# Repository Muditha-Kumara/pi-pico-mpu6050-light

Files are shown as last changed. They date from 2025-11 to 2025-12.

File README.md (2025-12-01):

# Motion Light Pico Hat

Motion Light Pico Hat Icon

An interactive dual-core LED "water flow" and tilt simulation for the Raspberry Pi Pico / Pico 2 using a WS2812B LED strip and an MPU-6050 IMU (or a built‑in software tilt simulator when the sensor is absent). The project demonstrates:

- Dual-core coordination on RP2040 (Core 0: sensor / simulation; Core 1: LED rendering + serial output)
- Smooth physics-like motion (velocity, damping, bounce) converted to a glowing LED blob that shifts and reflects within the strip
- ASCII real-time visualization in the Serial Monitor for debugging without LEDs
- Seamless fallback to simulated tilt if the accelerometer is not detected

## Supported Boards

| Board | PlatformIO Environment | Arduino IDE Board | Notes |
|---|---|---|---|
| Raspberry Pi Pico (RP2040) | `pico_official` | "Raspberry Pi Pico" (Earle Philhower core) | Fully supported |
| Raspberry Pi Pico 2 (RP2350) | `rpipico2_project` | "Raspberry Pi Pico 2" (Earle Philhower core) | Use with updated RP2350 core; see below |

*Pico 2 support uses the RP2350 chip. Logic and pin usage are identical. To enable, adjust `platformio.ini` and ensure the correct board/platform is selected.*

> **Development Note:**
> This project was requested for the original Raspberry Pi Pico (RP2040). However, all development and testing were performed on a Raspberry Pi Pico 2 (RP2350) board. The code is fully compatible with the normal Pico board and was written to ensure it works on both models. If you use a Pico 2, select the correct environment in [`platformio.ini`](./platformio.ini) or Arduino IDE as described above.

## Features

- Real-time LED physics (position, velocity, damping, reflection)
- Adaptive glow with Gaussian/exponential falloff and shimmer
- Dual-core separation: deterministic LED refresh at ~30 FPS independent of sensor loop (~50 Hz)
- Automatic hardware detection for MPU‑6050 at I2C address `0x68`; simulation fallback if absent
- Lightweight inter-core communication (volatile globals)

## Directory Structure

```
.
├── platformio.ini      # PlatformIO build configuration
├── src/
│   └── main.cpp        # Main application source (dual-core logic, PlatformIO)
├── MotionLightPicoHat_Arduino/
│   └── MotionLightPicoHat_Arduino.ino # Arduino IDE-friendly sketch (identical logic)
├── lib/                # (Optional) user libraries
├── include/            # (Optional) project headers
├── PCB/                # Hardware design files and outputs
│   ├── pico.kicad_sch      # KiCad schematic
│   ├── pico.kicad_pcb      # KiCad PCB layout
│   ├── pico.kicad_pro      # KiCad project settings
│   ├── pico.kicad_prl      # KiCad project local settings (ignore in git)
│   ├── PCB_Print/          # Gerber and drill files for manufacturing
│   │   └── pico-PCB(gbr).zip # Gerber/drill manufacturing archive for PCB fabrication
│   └── Assets/             # PCB-related images and logos
├── assets/             # Icons and images for documentation
├── README.md           # This documentation
├── LICENSE             # Project license
```

- [`MotionLightPicoHat_Arduino/`](./MotionLightPicoHat_Arduino/.) contains an Arduino IDE-friendly [`.ino`](./MotionLightPicoHat_Arduino/MotionLightPicoHat_Arduino.ino) file for easy use. Open this folder and file directly in Arduino IDE for the same functionality as [`src/main.cpp`](./src/main.cpp).

- [`PCB/`](./PCB/) contains all hardware design files: schematic, PCB layout, project settings, gerbers (in [`PCB_Print/`](./PCB/PCB_Print/)) and images.

## Hardware Requirements
## PCB Details
#### I2C Address Selection

The PCB includes a J4 jumper, which can be used to select the I2C address of the MPU-6050 sensor. By bridging or leaving J4 open, you can choose between the two standard MPU-6050 I2C addresses (0x68 or 0x69). Refer to the silkscreen and schematic for the correct configuration for your sensor module.

**Note:** The PCB is designed specifically for the original Raspberry Pi Pico (RP2040), not Pico 2. Pinout and mechanical fit are for the standard Pico board only.

This project includes a custom PCB designed for the Raspberry Pi Pico, WS2812B LED strip, and MPU-6050 IMU. The PCB provides:

- Direct Pico header footprint (solder Pico)
- Onboard or external MPU-6050 support (I2C)
- Dedicated LED strip connector (5V, GND, DIN)
- 5V power input (max 5A) and distribution
- Clear silkscreen labels for all connections

### PCB Images

**Top View (Silkscreen):**

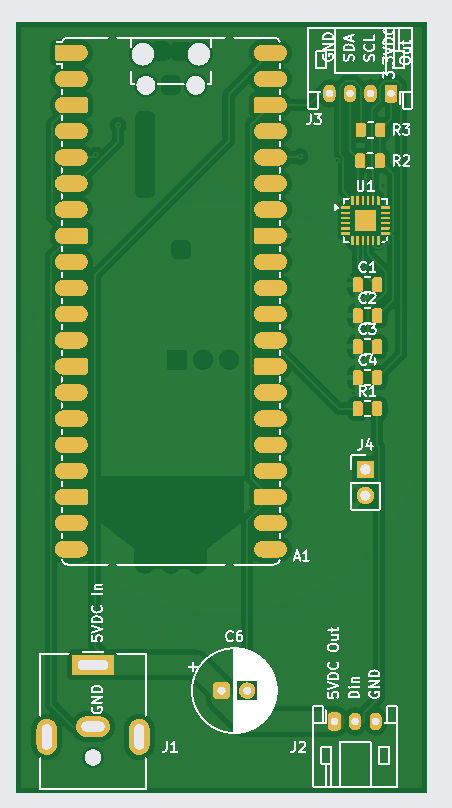
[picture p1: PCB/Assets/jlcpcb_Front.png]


**Bottom View (Component Side):**

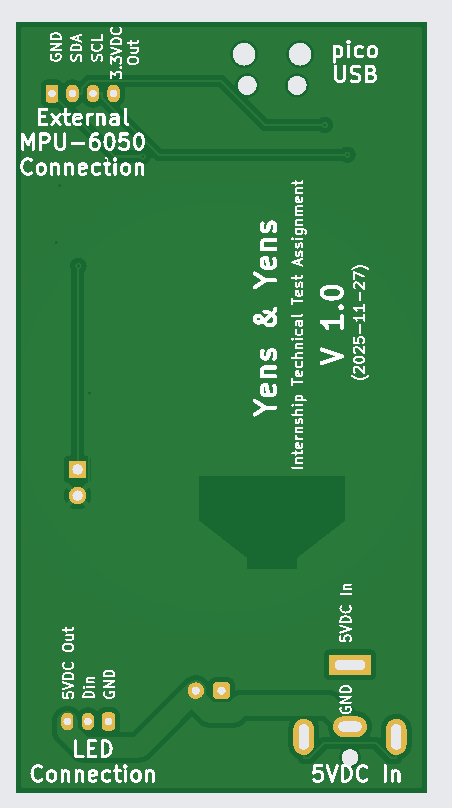
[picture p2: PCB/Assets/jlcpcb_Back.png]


> _Images above: Top shows silkscreen labels and external connections; bottom shows Pico header, MPU-6050 footprint, and connectors._

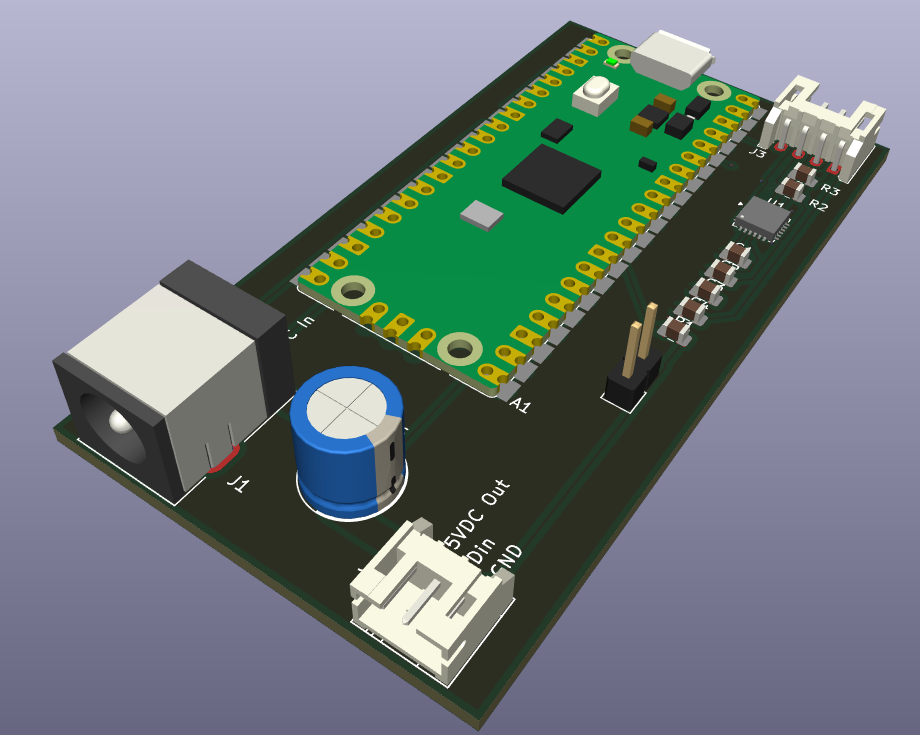
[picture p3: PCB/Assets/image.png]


### Key Connections

- **External MPU-6050:**
   - GND, VCC, SDA, SCL pins for external IMU module
- **LED Connection:**
   - 5VDC Out, Din (GPIO 22), GND for WS2812B strip
- **5VDC In:**
   - Main power input for LEDs and Pico
- **Pico USB:**
   - For programming and optional power

### Assembly Notes

- Ensure correct orientation of the Pico and all connectors.
- Use the onboard or external MPU-6050 as needed.
- Always connect GND between Pico, LED strip, and power supply.

PCB design files and [Gerbers](./PCB/PCB_Print/pico-PCB(gbr).zip) are in the [`PCB/`](./PCB/.) directory for manufacturing or modification.

| Component | Purpose | Notes |
|---|---|---|
| Raspberry Pi Pico| MCU | USB power + programming |
| WS2812B LED strip (30 LEDs) | Visual effect | Data pin connected to GPIO 22 |
| MPU-6050 IMU (optional) | Tilt sensing | I2C at `0x68` on GPIO 4 (SDA) and GPIO 5 (SCL) |
| Power supply (5V recommended) | LED power | Ensure common ground with Pico |

### Pin Mapping

| Signal | RP2040 GPIO | Description |
|---|---|---|
| LED Data | 22 | WS2812B DIN |
| I2C SDA | 4 | MPU-6050 SDA |
| I2C SCL | 5 | MPU-6050 SCL |

## Software Dependencies

- [FastLED](https://github.com/FastLED/FastLED) (≥3.10.x) for LED control
- Wire (built-in with Arduino core) for I2C communication

Optional: Adafruit MPU6050 library is **not required** because raw register reads are used for robustness and minimal overhead.

## Serial Output Compatibility (PlatformIO vs Arduino IDE)

The code supports both single-line (overwriting) and multi-line serial output for compatibility with different serial monitors:

- **Single-line output** (default, works in PlatformIO and most advanced terminals):
   - Set `#define USE_CARRIAGE_RETURN 1` at the top of [`src/main.cpp`](./src/main.cpp).
   - Output will always overwrite the same line, giving a live-updating effect.
- **Multi-line output** (for Arduino IDE Serial Monitor):
   - Set `#define USE_CARRIAGE_RETURN 0` at the top of [`src/main.cpp`](./src/main.cpp).
   - Each update prints on a new line (Arduino IDE Serial Monitor does not support carriage return overwrite).

**How to switch:**

```cpp
#define USE_CARRIAGE_RETURN 1 // or 0 for Arduino IDE
```

This macro is at the top of [`src/main.cpp`](./src/main.cpp). Change it as needed for your environment.

## Dual-Core Flow Overview

| Core | Function | Key Loop Rate |
|---|---|---|
| Core 0 (`setup()` / `loop()`) | I2C sensor read or simulation | ~50 Hz (20 ms delay) |
| Core 1 (`setup1()` / `loop1()`) | LED physics + rendering + ASCII output | ~30 FPS (33 ms delay) |

Synchronization uses simple `volatile` variables (`g_tilt_x`, `g_sensor_connected`). For production-grade systems with higher complexity, use mutexes or queues.

## Building with PlatformIO

### 1. Prerequisites

- PlatformIO Core or VS Code + PlatformIO extension installed

### 2. Key [`platformio.ini`](./platformio.ini) Excerpt

```ini
[env:pico_official]
platform = https://github.com/maxgerhardt/platform-raspberrypi.git
board = pico
framework = arduino
board_build.core = earlephilhower
monitor_speed = 115200
lib_deps = Wire, FastLED

[env:rpipico2_project]
platform = https://github.com/maxgerhardt/platform-raspberrypi.git
board = rpipico2
framework = arduino
board_build.core = earlephilhower
monitor_speed = 115200
lib_deps =Wire, FastLED
```

### 3. Build & Upload

```bash
# Build
platformio run -e pico_official

# (Optional) Clean
platformio run -e pico_official -t clean

# Upload (UF2 drag-and-drop or configured uploader)
platformio run -e pico_official -t upload
```

If using UF2: hold BOOTSEL while plugging the Pico, then copy the generated `firmware.uf2` from `.pio/build/pico_official/` to the mounted drive.

### 4. Monitor Serial Output

```bash
platformio device monitor -e pico_official --baud 115200
```

You will see a single updating line like:

```text
[H/W] Tilt (X): -0.12 | Pos: 15.44 | Flow: [   __====~~~~====__   ]
```

`[SIM]` indicates the fallback simulation mode when the sensor is absent.

## Using Arduino IDE Instead

1. Open Arduino IDE (2.x recommended).
2. Preferences → Additional Boards Manager URLs:
   - `https://github.com/earlephilhower/arduino-pico/releases/download/global/package_rp2040_index.json`
3. Boards Manager: install "RP2040" (Earle Philhower).
4. Board: Tools → Board → Raspberry Pi RP2040 Boards → Raspberry Pi Pico (or Pico 2).
5. Open [`MotionLightPicoHat_Arduino/MotionLightPicoHat_Arduino.ino`](./MotionLightPicoHat_Arduino/MotionLightPicoHat_Arduino.ino) directly in Arduino IDE (recommended), or copy code from [`src/main.cpp`](./src/main.cpp) if you want to create your own sketch. Both files are kept in sync and provide the same functionality (including dual-core support with `setup1()` / `loop1()`).
6. Library Manager: install FastLED.
7. Upload:
   - Default: Hold BOOTSEL, plug in, then Upload.
   - Optional: Select Picotool method if installed.
8. Open Serial Monitor @ 115200 baud.

## LED Animation Logic

1. Read tilt acceleration (real or simulated) → scaled to influence velocity.
2. Apply damping & clamp velocity.
3. Integrate velocity → position of the "water mass".
4. Bounce at ends with energy loss (`BOUNCE_DAMPING`).
5. Glow profile: `intensity = exp(-distance * GLOW_DECAY)` plus shimmer sine term.
6. Map intensity to color scaling on `CRGB WATER_COLOR`.

## Extending the Project

| Idea | Description |
|---|---|
| Add Y/Z tilt | Expand to 2D matrix or color modulation |
| Sensor fusion | Incorporate complementary filter for stable angles |
| Persistent config | Store brightness or mode in flash/EEPROM |
| Multi-effect engine | Switch between "water", "fire", "sparkle" modes via serial commands |

## Troubleshooting

| Symptom | Possible Cause | Fix |
|---|---|-----|
| `Arduino.h` missing (PlatformIO) | Wrong platform core | Use Earle Philhower core via custom platform URL as shown |
| All LEDs off | Power issue or brightness too low | Confirm 5V supply & `FastLED.setBrightness()` value |
| `[SIM]` always shown | Sensor not detected | Check wiring, address `0x68`, pull-ups on SDA/SCL |
| Flickering LEDs | Long wires or insufficient grounding | Add data line resistor (~330Ω), ensure shared ground |
| Serial gibberish | Baud mismatch | Use 115200 in monitor |

## Performance Notes

- RAM usage is minimal (<5%), leaving headroom for additional features.
- Using software glow math with simple `exp()` calls; performance acceptable for 30 LEDs at 30 FPS.
- FastLED auto-selects software SPI timing for WS2812B (normal).

## Safety & Power Considerations

- At full white, WS2812B LED strips can draw ~60mA/LED. This animation uses modest brightness (blue tint) but plan power budget (e.g., 30 LEDs ≈ 1.8A worst case).
- Always share ground between Pico and LED power.

## License

Add your chosen license (e.g., MIT, Apache-2.0) here. Example MIT header:

```text
Copyright (c) 2025 <Muditha Chinthana Kumara>
Permission is hereby granted, free of charge, to any person obtaining a copy...
```

## Acknowledgements

- Earle Philhower RP2040 Arduino core
- FastLED community
- Documentation generated with AI assistance (GitHub Copilot)

---

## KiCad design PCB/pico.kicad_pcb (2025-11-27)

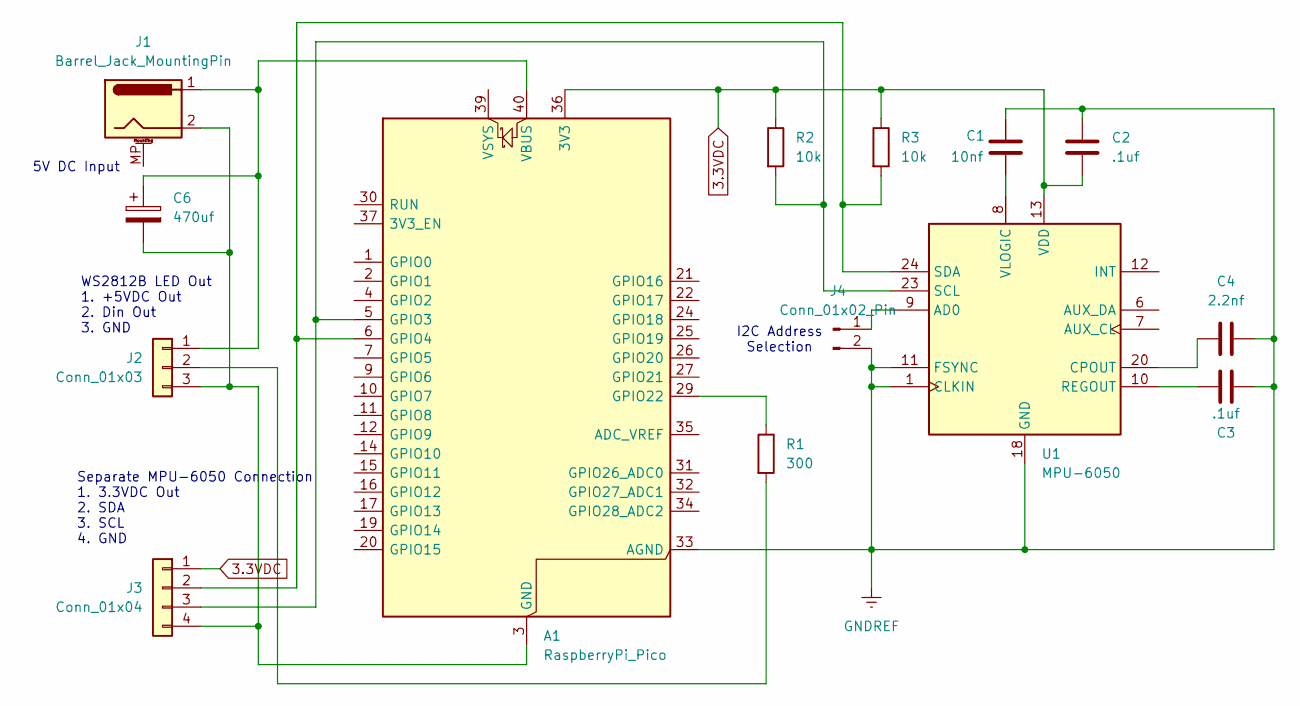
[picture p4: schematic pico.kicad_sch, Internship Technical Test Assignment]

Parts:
A1: RaspberryPi_Pico; RaspberryPi_Pico_Common_SMD
C1: 10nf; C_0805_2012Metric
C2, C3: .1uf; C_0805_2012Metric
C4: 2.2nf; C_0805_2012Metric
C6: 470uf; CP_Radial_D8.0mm_P2.50mm
J1: Barrel_Jack_MountingPin; BarrelJack_CUI_PJ-063AH_Horizontal
J2: Conn_01x03; JST_PH_S3B-PH-K_1x03_P2.00mm_Horizontal
J3: Conn_01x04; JST_PH_S4B-PH-K_1x04_P2.00mm_Horizontal
J4: Conn_01x02_Pin; PinHeader_1x02_P2.54mm_Vertical
R1: 300; C_0805_2012Metric
R2, R3: 10k; C_0805_2012Metric
U1: MPU-6050; HVQFN-24-1EP_4x4mm_P0.5mm_EP2.1x2.1mm

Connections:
3.3VDC: A1.36 (3V3), C2.2, J3.1, R2.1, R3.1, U1.13 (VDD)
GNDREF: A1.33 (AGND), C1.1, C2.1, C3.1, C4.1, J4.2, U1.1 (CLKIN), U1.11 (FSYNC), U1.18 (GND)
unnamed: A1.5 (GPIO3), J3.3, R2.2, U1.23 (SCL)
unnamed: A1.6 (GPIO4), J3.2, R3.2, U1.24 (SDA)
unnamed: A1.29 (GPIO22), R1.1
unnamed: A1.40 (VBUS), C6.1, J1.1, J2.1
unnamed: J2.2, R1.2
unnamed: A1.3 (GND), A1.8 (GND), A1.13 (GND), A1.18 (GND), A1.23 (GND), A1.28 (GND), A1.38 (GND), C6.2, J1.2, J2.3, J3.4
unnamed: J4.1, U1.9 (AD0)
unnamed: C4.2, U1.20 (CPOUT)
unnamed: C3.2, U1.10 (REGOUT)
unnamed: C1.2, U1.8 (VLOGIC)

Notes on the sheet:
I2C Address Selection
5V DC Input
WS2812B LED Out 1. +5VDC Out 2. Din Out 3. GND
Separate MPU-6050 Connection 1. 3.3VDC Out 2. SDA 3. SCL 4. GND

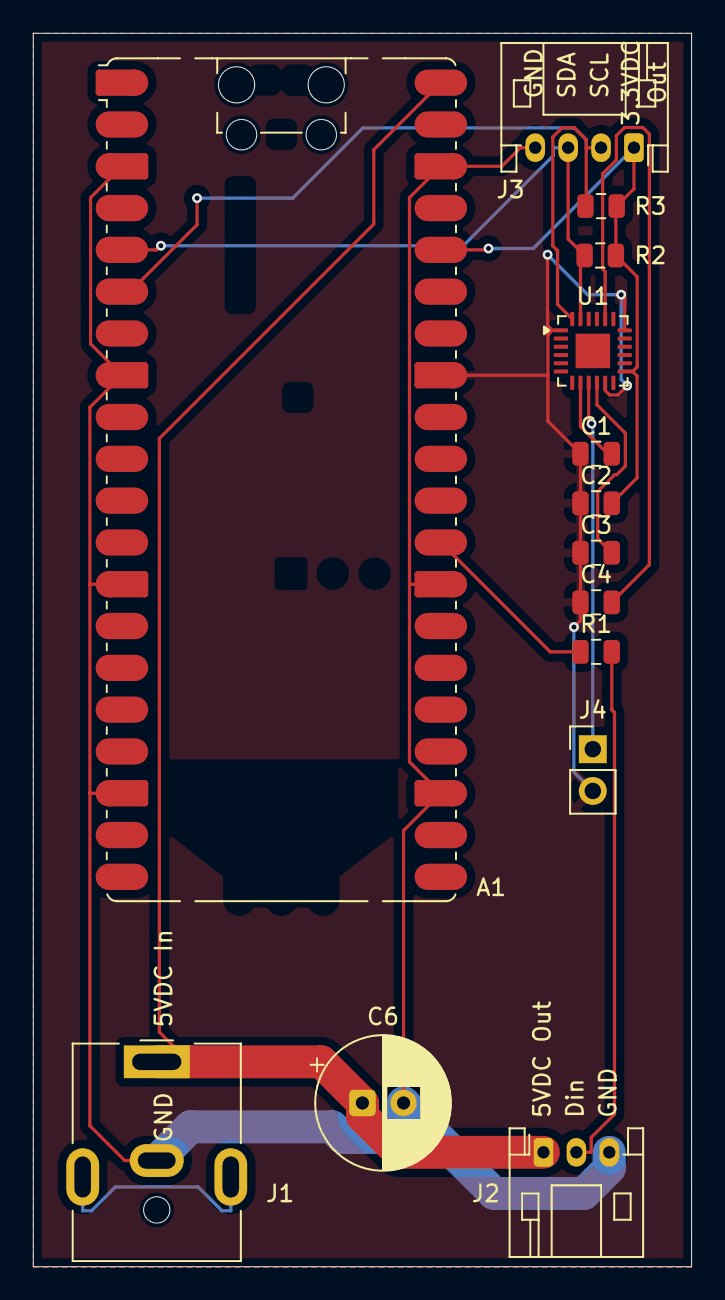
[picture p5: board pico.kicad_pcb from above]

Board: 2 copper layers, 40.0 x 75.0 mm, 14 parts (0 on the bottom side), 12 nets.

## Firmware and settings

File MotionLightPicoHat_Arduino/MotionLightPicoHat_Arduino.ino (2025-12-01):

// Set to 1 for single-line overwrite (PlatformIO, advanced terminals), 0 for multi-line (Arduino IDE)
#define USE_CARRIAGE_RETURN 0
/*
 * Board: Raspberry Pi Pico (RP2040, Earle Philhower)
 * Boards Manager URL: https://github.com/earlephilhower/arduino-pico/releases/download/global/package_rp2040_index.json
 * Library: FastLED, Wire (for I2C communication with MPU-6050)
 */
#include <Arduino.h>
#include <FastLED.h>
#include <Wire.h>

// --- HARDWARE CONFIGURATION ---
#define LED_PIN 22    // Data pin for the WS2812B strip
#define NUM_LEDS 30   // Total number of LEDs in the strip
#define MPU_ADDR 0x68 // MPU-6050 I2C address
#define SDA_PIN 4     // I2C SDA pin for MPU-6050
#define SCL_PIN 5     // I2C SCL pin for MPU-6050

// --- ANIMATION CONSTANTS ---
const float BOUNCE_DAMPING = 0.85; // Velocity retention on bounce (0.0 to 1.0)
const float MAX_VELOCITY = 1.0;    // Maximum speed of the water flow
const float GLOW_DECAY = 0.5;      // Glow intensity decay rate
const CRGB WATER_COLOR = CRGB::Blue;

const int ASCII_STRIP_LENGTH = NUM_LEDS; // Length for Serial Monitor visualization

// --- SHARED DATA (Accessed by both cores) ---
// Note: For production code, use proper synchronization (mutex/spin-lock)
// Simple volatile variables are used here for inter-core communication

volatile float g_tilt_x = 0.0;            // Tilt value from MPU-6050 or simulator
volatile bool g_sensor_connected = false; // MPU-6050 connection status

// --- CORE 1 VARIABLES (LED and Visualization) ---
CRGB leds[NUM_LEDS];
float water_pos = (float)NUM_LEDS / 2.0; // Floating point position of water mass
float water_vel = 0.0;                   // Velocity of water flow
float flow_time_offset = 0.0;            // Time offset for shimmer effect

// =================================================================================
// CORE 0: SENSOR READING AND SIMULATION
// =================================================================================

// Read X-axis acceleration from MPU-6050
bool read_mpu6050(float &accX)
{
    Wire.beginTransmission(MPU_ADDR);
    Wire.write(0x3B); // ACCEL_XOUT_H register
    if (Wire.endTransmission(true) != 0)
    {
        return false; // I2C communication failed
    }

    if (Wire.requestFrom(MPU_ADDR, 6, true) != 6)
    {
        return false; // Not enough data received
    }

    int16_t rawX = Wire.read() << 8 | Wire.read();
    // int16_t rawY = Wire.read() << 8 | Wire.read();
    // int16_t rawZ = Wire.read() << 8 | Wire.read();

    // Convert to G's (±2G range, 16384 LSB/G)
    accX = (float)rawX / 16384.0;
    return true;
}

void setup()
{
    // Core 0 initializes I2C and attempts to find the sensor
    Wire.setSDA(SDA_PIN);
    Wire.setSCL(SCL_PIN);
    Wire.begin();
    delay(100); // Allow I2C to stabilize

    // Check if MPU-6050 is present
    Wire.beginTransmission(MPU_ADDR);
    if (Wire.endTransmission(true) == 0)
    {
        // Wake up MPU-6050 (starts in sleep mode)
        Wire.beginTransmission(MPU_ADDR);
        Wire.write(0x6B); // PWR_MGMT_1 register
        Wire.write(0x00); // Wake up (clear sleep bit)
        Wire.endTransmission(true);

        delay(50); // Allow sensor to wake up

        g_sensor_connected = true;
    }
    else
    {
        g_sensor_connected = false;
    }
}

void loop()
{
    // Read/Simulate sensor data and update the shared variable
    if (g_sensor_connected)
    {
        // --- Hardware Reading ---
        float new_accel_x;
        if (read_mpu6050(new_accel_x))
        {
            g_tilt_x = new_accel_x;
        }
    }
    else
    {
        // --- Simulated Fallback ---
        // Simulate a slow, gentle oscillation in tilt
        // Time-based wave movement
        float time_sec = millis() / 1000.0;
        // Oscillate between -1.0 G and +1.0 G tilt
        g_tilt_x = sin(time_sec * 0.5) * 0.8;
    }

    // Core 0 loop delay
    delay(20); // Read sensor/simulate at ~50Hz
}

// =================================================================================
// CORE 1: LED CONTROL AND SERIAL MONITOR
// =================================================================================

void setup1()
{
    // Core 1 initializes the LED strip and Serial Monitor
    FastLED.addLeds<WS2812B, LED_PIN, GRB>(leds, NUM_LEDS);
    FastLED.setBrightness(150);
    Serial.begin(115200);
}

// Update LED animation based on physics simulation
void update_led_strip()
{
    // 1. Physics Update
    float tilt_accel = g_tilt_x * 0.2; // Scale down the tilt value for animation sensitivity
    water_vel += tilt_accel;           // Apply gravity/tilt to velocity

    // Apply friction/drag to velocity
    water_vel *= 0.98;

    // Clamp velocity to prevent hyper-speed flow
    water_vel = constrain(water_vel, -MAX_VELOCITY, MAX_VELOCITY);

    // Update position
    water_pos += water_vel;

    // 2. Edge Reflection/Bounce Logic
    if (water_pos < 0)
    {
        water_pos = 0;
        water_vel = -water_vel * BOUNCE_DAMPING; // Reverse and dampen velocity
    }
    else if (water_pos >= NUM_LEDS)
    {
        water_pos = (float)NUM_LEDS - 0.001;     // Back just inside the edge
        water_vel = -water_vel * BOUNCE_DAMPING; // Reverse and dampen velocity
    }

    // 3. Clear strip and apply new glow
    FastLED.clear();

    // Update shimmer offset
    flow_time_offset += 0.05;

    for (int i = 0; i < NUM_LEDS; i++)
    {
        // Calculate distance from the water's center (water_pos)
        float dist = abs(i - water_pos);

        // Exponential/Gaussian decay for the glow intensity
        float intensity = exp(-dist * GLOW_DECAY);

        // Apply shimmer (fun touch)
        // Add a sine wave based on flow position and time for a subtle sparkle/shimmer
        float shimmer = sin((i * 0.3) + flow_time_offset) * 0.2 + 0.8;
        intensity *= shimmer;

        // Apply color and intensity
        CRGB color = WATER_COLOR;
        color.nscale8(intensity * 255); // Scale color by intensity (0-255)

        leds[i] = color;
    }
}

// Generate ASCII visualization for Serial Monitor
void create_ascii_visualization(char *buffer, int buffer_size)
{
    if (buffer_size < NUM_LEDS + 1)
        return;

    for (int i = 0; i < NUM_LEDS; i++)
    {
        // Get the brightness of the LED (V in HSV, or just max R/G/B here)
        uint8_t brightness = max(max(leds[i].r, leds[i].g), leds[i].b);

        if (brightness > 180)
        {
            buffer[i] = '~'; // Bright water glow
        }
        else if (brightness > 50)
        {
            buffer[i] = '='; // Medium glow/water body
        }
        else if (brightness > 10)
        {
            buffer[i] = '_'; // Background/dim edge
        }
        else
        {
            buffer[i] = ' '; // Off/empty space
        }
    }
    buffer[NUM_LEDS] = '\0'; // Null terminate
}

void loop1()
{
    // 1. Update LED State
    update_led_strip();

    // 2. Show LEDs
    FastLED.show();

    // 3. Serial Monitoring (single-line or multi-line, depending on macro)
    static char ascii_visual[NUM_LEDS + 1]; // Static buffer for ASCII visualization
    create_ascii_visualization(ascii_visual, sizeof(ascii_visual));

#if USE_CARRIAGE_RETURN
    Serial.print('\r'); // Overwrite line (works in PlatformIO, most terminals)
#else
    Serial.println(); // New line (works in Arduino IDE Serial Monitor)
#endif
    Serial.print(g_sensor_connected ? "[H/W]" : "[SIM]");
    Serial.print(" Tilt (X): ");
    Serial.print(g_tilt_x, 2);
    Serial.print(" | Pos: ");
    Serial.print(water_pos, 2);
    Serial.print(" | Flow: [");
    Serial.print(ascii_visual);
    Serial.print("] ");

    // Core 1 loop delay
    delay(33); // Run animation/display at ~30 FPS
}

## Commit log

2025-11-24 Add PCB design files for project hardware
    [pico-B_Adhesive.gbr, pico-B_Cu.gbr, pico-B_Mask.gbr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]
2025-11-25 Add Version !.0
    [pico-B_Adhesive.gbr, pico-B_Cu.gbr, pico-B_Mask.gbr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]
2025-11-27 Ready for final submition
    [pico-B_Adhesive.gbr, pico-B_Cu.gbr, pico-B_Mask.gbr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]
2025-11-30 Add PCB details and assembly notes to README.md
2025-11-30 add pcb image and link
2025-12-01 Update board and library information in the Arduino file
